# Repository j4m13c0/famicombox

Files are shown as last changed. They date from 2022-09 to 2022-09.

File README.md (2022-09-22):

Main Board

The FamicomBox+ mod has been designed to fix some of the design limitations in the Famicom Box design. The Famicom Box is designed to switch between 16 different cartridges, however in the original design some of the pins in the cartridge are common between the 16 cartridges such as IRQ, M2 and PPU /RD. This mod addresses the following issues:

* Demultiplexes M2 (Pin 38) to all 16 Cartridges
* Multiplexes /IRQ (Pin 15) from all 16 cartridges
* Multiplexes CIRAM /CE (Pin 57) from all 16 cartirdges
* Demultiplexes PPU A12 (pin 64) to all 16 Cartridges
* Demultiplexes PPU /RD (Pin 21) to all 16 Cartridges
* Supplies PPU /A13 (Pin 58) to all cartridges
* Isolates EXP0, EXP1, EXP2, EXP3, EXP4, EXP5, EXP7, EXP8 and EXP9 
* Allows 2 cartridges to utilise EXP6 for Expansion Audio with volume control. 
* Fixes an issue with open bus on games such as Paper Boy
* Disables the second RAM chip 6000 - 7FFF when in game, to allow SRAM and other functions. 
* Enables / Disables $5xxx when in game, this is used in some games and the Everdrive. 

### Famicom Box Warning

On a stock Famicom Box, the EXP Lines are connected to 5V or GND depending on which slot you use. This is used with the CIC to address each CIC individually. Some cartridges use these ports for debugging, Audio etc. If you have a stock Famicom Box you will damage certain cartridge if you plug them in.

### Limitations
This mod is rather complicated to install as there are many parts that you will need to modify to get it to work. You will need to have prior experience with de-soldering IC chips, soldering mod wires and debugging any issues that arise. 
This mod will not work with modern games that have tighter timings, as well as bootleg games bought from places such as AliExpress. 

### Tested Games
I have tested this with the following games:

* Castlevania 3 (Famicom with Expansion Audio)
* The Legend of Zelda
* The Adventure of Link
* Super Mario Bros
* Super Mario Bros 2
* Super Mario Bros 3
* Gauntlet II
* Tetris
* Snake Rattle N Roll
* The Little Mermaid
* Excitebike
* Tennis
* Duck Hunt
* Wrecking Crew
* Captain Planet and the Planeteers
* High Speed
* Yoshi 

I have also been able to use the Famicom Disk System, the RAM adapter will fit in Slot 14. The mod also works with an Everdrive. 

__There may be some games that will not work on this system. This could be down to timing issues. I cannot guarantee any game will work outside of the games tested.__

### Menu System 
The Menu system has been designed by Nintendo to check an internal database of games or for the Nintendo Header in the ROM. Most games do not have a correct header and will not be in the database, thus the game will be rejected. 
 
To get around this, we have modified the menu to still allow games to show up in the menu, however it will only display "NES GAME" instead of the actual game name. 

### 3D Prints
I have included some 3D prints that have used with the Famicom Box.  
 
The Modulator 3D print I used to replace the modulator with some custom connectors with my Famicom Box, I had fitted an NESRGB and this was where I mounted the video and audio connections. This is not required, but added incase you also want to RGB yours. 

The Replacement Coin box covers are the 2 covers on the right-hand side. If you remove the coinbox, you will need these to cover up the holes. 

The 72 Pin connector spacer is helpful if you use the Aliexpress connectors. See the installation guide for more details. 

### Special Thanks

I would like to thank Lidnariq for his time and knowledge to help me make this idea a reality, he was there to teach me what parts were different between the Famicom Box and what parts to include on my mod board. 

I would also like to extend a thank you to Fiskbit, who has helped with reverse engineering the Menu software and modifying it to allow other games to function. He has also improved the menu and fixed some bugs. 
The boot up of the console is now drastically improved due to changes made to the menu.

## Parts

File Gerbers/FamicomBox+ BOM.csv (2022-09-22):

Part | Value | Mouser PN
C1 | 100nF | 581-06035C104KAT2A
C2 | 100nF | 581-06035C104KAT2A
C3 | 100nF | 581-06035C104KAT2A
C4 | 100nF | 581-06035C104KAT2A
C5 | 100nF | 581-06035C104KAT2A
C6 | 100nF | 581-06035C104KAT2A
C7 | 100nF | 581-06035C104KAT2A
C8 | 100nF | 581-06035C104KAT2A
C9 | 100nF | 581-06035C104KAT2A
C10 | 100nF | 581-06035C104KAT2A
C12 | 100nF | 581-06035C104KAT2A
C13 | 100nF | 581-06035C104KAT2A
C15 | 100nF | 581-06035C104KAT2A
C16 | 100nF | 581-06035C104KAT2A
IC1 | 74HC138PW,118 | 771-74HC138PW-T
IC2 | 74HC138PW,118 | 771-74HC138PW-T
IC3 | SN74HC251NSR | 595-SN74HC251NSR
IC4 | SN74HC251NSR | 595-SN74HC251NSR
IC5 | MC74HC04ADG | 863-MC74HC04ADG
IC6 | SN74CBT3245APWR | 595-SN74CBT3245APWR
IC7 | SN74CBT3245APWR | 595-SN74CBT3245APWR
IC8 | SN74CBT3245APWR | 595-SN74CBT3245APWR
IC9 | SN74HC251NSR | 595-SN74HC251NSR
IC10 | SN74HC251NSR | 595-SN74HC251NSR
IC11 | SN74ALS138AN | 595-SN74ALS138AN
IC12 | CD74HC238PWR | 595-CD74HC238PWR
IC13 | CD74HC238PWR | 595-CD74HC238PWR
IC16 | 74HC138PW,118 | 771-74HC138PW-T
IC17 | 74HC138PW,118 | 771-74HC138PW-T
J1 | Pin Strip
J2 | Pin Strip
J3 | Pin Strip
J4 | Pin Strip
J5 | Pin Strip
J6 | Pin Strip
J7 | Pin Strip
J8 | Pin Strip
J9 | 2-5499206-1 | 571-2-5499206-1
J9 Cable Conn | 1658527-4 | 571-1658527-4
J10 | 2-5499206-6 | 571-2-5499206-6
J10 Cable Conn | 1-1658527-0 | 571-1-1658527-0
J11 | 2-5499206-6 | 571-2-5499206-6
J11 Cable Conn | 1-1658527-0 | 571-1-1658527-0
J12 | 2-5499206-6 | 571-2-5499206-6
J12 Cable Conn | 1-1658527-0 | 571-1-1658527-0
R1 | PTV09A-4020F-A504 | 652-PTV09A-4020FA504
R2 | 1.5K | CR0603-FX-1501ELF
R3 | 1.5K | CR0603-FX-1501ELF
RN1 | CAY17-103JALF | 652-CAY17-103JALF
RN2 | CAY17-103JALF | 652-CAY17-103JALF
RN3 | 4816P-T01-101LF | 652-4816P-T1LF-100
RN4 | 4816P-T01-101LF | 652-4816P-T1LF-100
RN5 | 4816P-T01-101LF | 652-4816P-T1LF-100

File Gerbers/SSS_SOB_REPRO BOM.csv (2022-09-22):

Part | Value | Mouser
C1 | 100nf | 581-06035C104KAT2A
C2 | 100nf | 581-06035C104KAT2A
C3 | 100nf | 581-06035C104KAT2A
C4 | 100nf | 581-06035C104KAT2A
C5 | 100nf | 581-06035C104KAT2A
C6 | 100nf | 581-06035C104KAT2A
C7 | 100nf | 581-06035C104KAT2A
C8 | 100nf | 581-06035C104KAT2A
C9 | 220uf 10V | 647-UFW1A221MED
C10 | 220uf 10V | 647-UFW1A221MED
J1 | 2-5499206-6 | 571-2-5499206-6
J1 Cable Conn | 1-1658527-0 | 571-1-1658527-0
J2 | 2-5499206-6 | 571-2-5499206-6
J2 Cable Conn | 1-1658527-0 | 571-1-1658527-0
J3 | 2-5499206-6 | 571-2-5499206-6
J3 Cable Conn | 1-1658527-0 | 571-1-1658527-0
P1 | CARTRIDGE_CONNECTOR | https://www.aliexpress.com/item/32785406388.html
P2 | CARTRIDGE_CONNECTOR | https://www.aliexpress.com/item/32785406388.html
P3 | CARTRIDGE_CONNECTOR | https://www.aliexpress.com/item/32785406388.html
P4 | CARTRIDGE_CONNECTOR | https://www.aliexpress.com/item/32785406388.html
P5 | CARTRIDGE_CONNECTOR | https://www.aliexpress.com/item/32785406388.html
P6 | CARTRIDGE_CONNECTOR | https://www.aliexpress.com/item/32785406388.html
P7 | CARTRIDGE_CONNECTOR | https://www.aliexpress.com/item/32785406388.html
P8 | CARTRIDGE_CONNECTOR | https://www.aliexpress.com/item/32785406388.html
P9 | CARTRIDGE_CONNECTOR | https://www.aliexpress.com/item/32785406388.html
P10 | CARTRIDGE_CONNECTOR | https://www.aliexpress.com/item/32785406388.html
P11 | CARTRIDGE_CONNECTOR | https://www.aliexpress.com/item/32785406388.html
P12 | CARTRIDGE_CONNECTOR | https://www.aliexpress.com/item/32785406388.html
P13 | CARTRIDGE_CONNECTOR | https://www.aliexpress.com/item/32785406388.html
P14 | CARTRIDGE_CONNECTOR | https://www.aliexpress.com/item/32785406388.html
P15 | CARTRIDGE_CONNECTOR | https://www.aliexpress.com/item/32785406388.html
P16 | CARTRIDGE_CONNECTOR | https://www.aliexpress.com/item/32785406388.html
P17 | CARTRIDGE_CONNECTOR | https://www.aliexpress.com/item/32785406388.html
P18 | CARTRIDGE_CONNECTOR | https://www.aliexpress.com/item/32785406388.html
P19 | LED_BOARD_CONNECTOR | B7B-PH-K-S(LF)(SN)
P20 | LED_BOARD_CONNECTOR | B7B-PH-K-S(LF)(SN)
P21 | LED_BOARD_CONNECTOR | B7B-PH-K-S(LF)(SN)

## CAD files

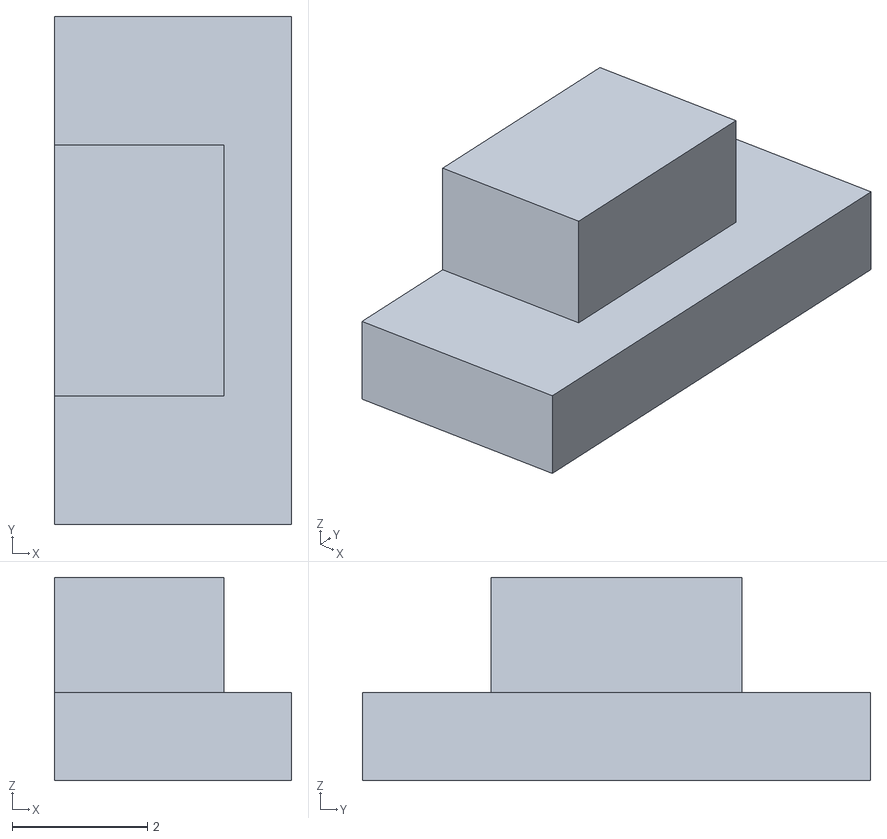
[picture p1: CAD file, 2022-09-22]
3D Models/72Pin Connector Spacer/72pin Insert v1.stl
3.50 x 7.50 x 3.00

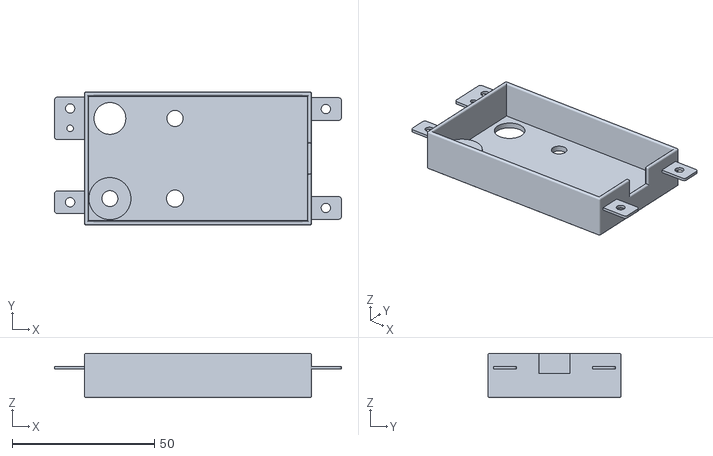
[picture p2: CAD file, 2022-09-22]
3D Models/Modulator/Modulator Famicom Box v7.stl
101.0 x 46.8 x 15.5

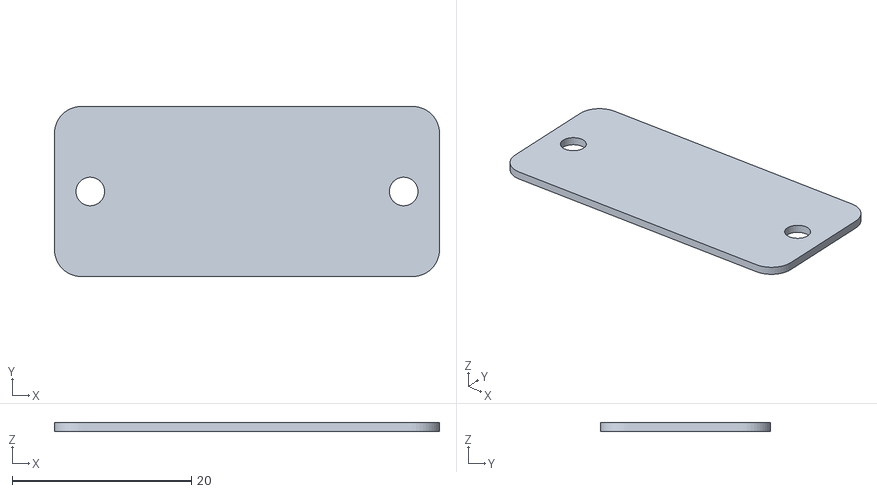
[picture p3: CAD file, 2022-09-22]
3D Models/Replacement Coin box Cover/Famicom Box Coinbox Cover Small v1.stl
43.0 x 19.0 x 1.00

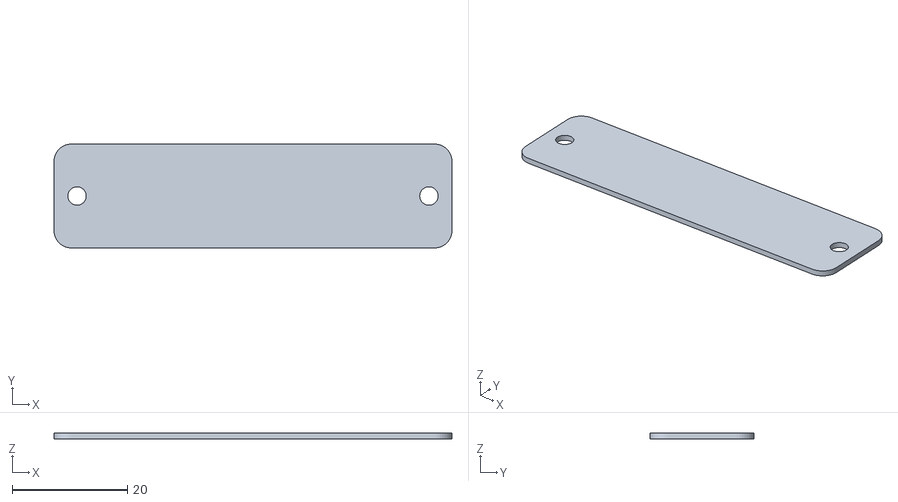
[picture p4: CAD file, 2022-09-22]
3D Models/Replacement Coin box Cover/Famicom Box Coinbox Cover Large v1.stl
69.0 x 18.0 x 1.00

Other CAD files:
3D Models/72Pin Connector Spacer/72pin Insert v1.f3d
3D Models/Modulator/Modulator Famicom Box v7.f3d
3D Models/Replacement Coin box Cover/Famicom Box Coinbox Cover Large v1.f3d
3D Models/Replacement Coin box Cover/Famicom Box Coinbox Cover Small v1.f3d

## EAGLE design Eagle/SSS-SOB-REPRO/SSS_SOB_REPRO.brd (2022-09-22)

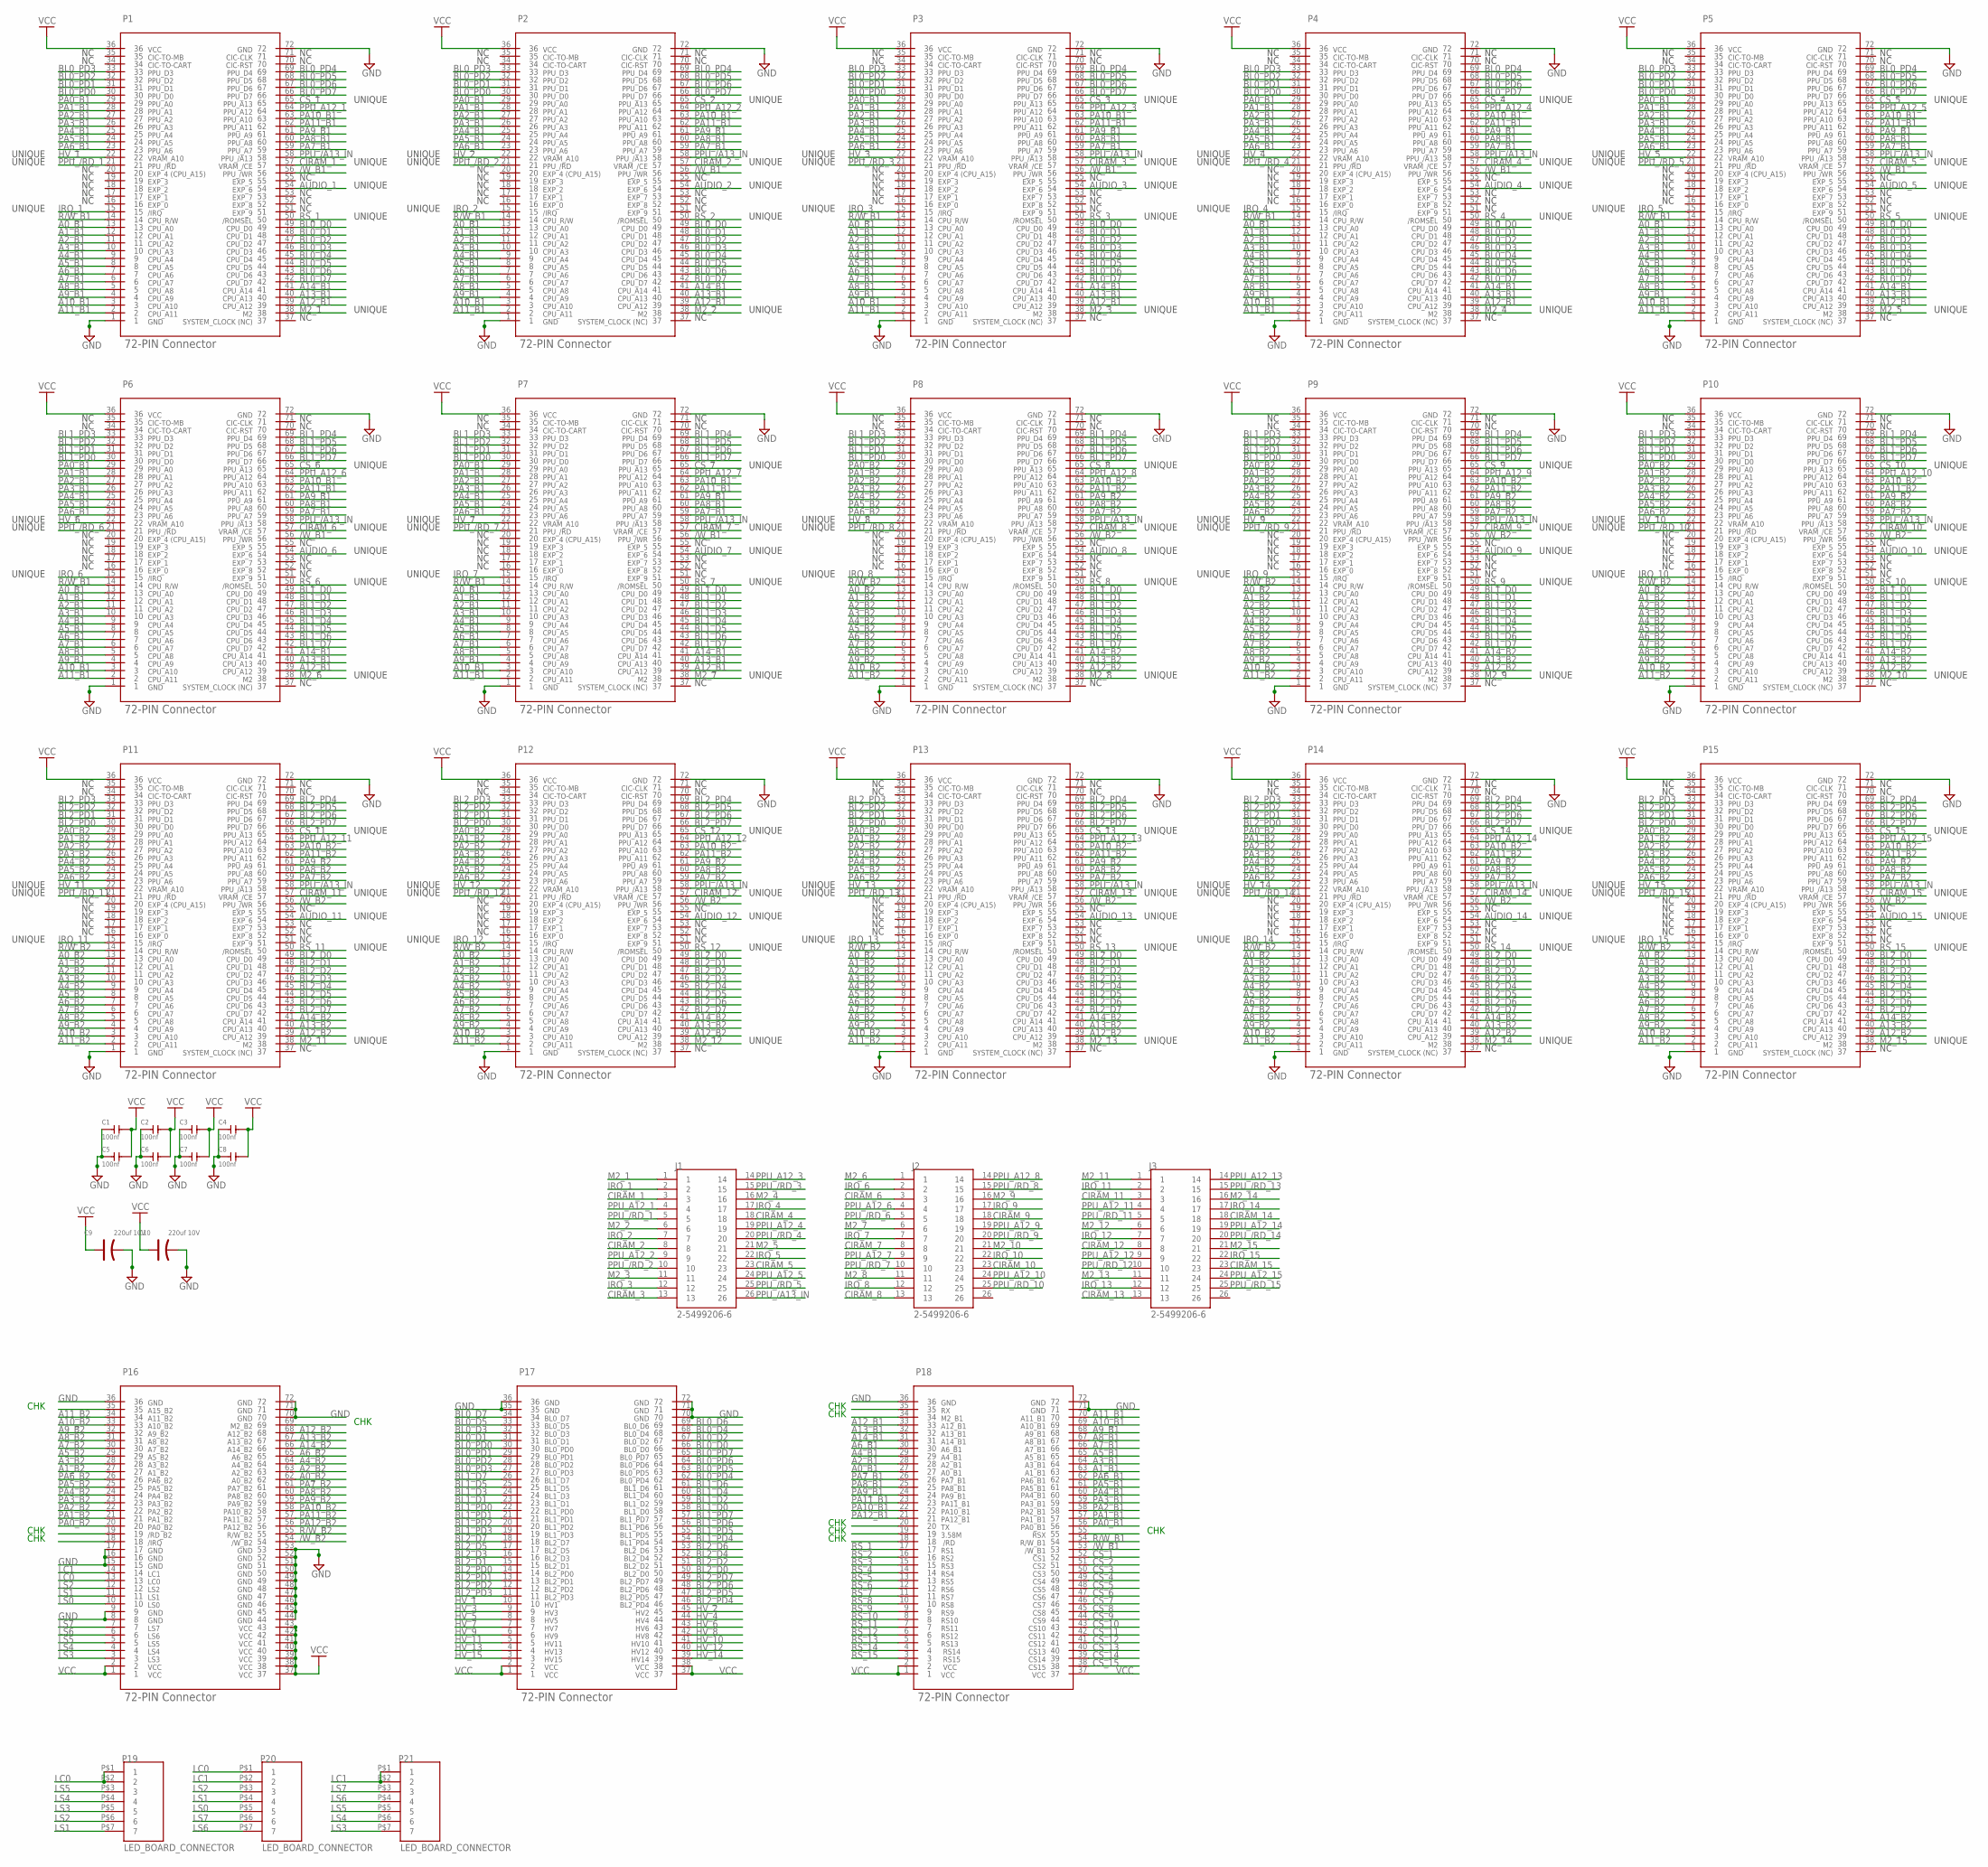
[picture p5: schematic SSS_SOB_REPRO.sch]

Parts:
C1, C2, C3, C4, C5, C6, C7, C8: 100nf; C0603
C9, C10: 220uf 10V; PC-D5.3MM
J1, J2, J3: 2-5499206-6; TE_2-5499206-6
P1, P2, P3, P4, P5, P6, P7, P8, P9, P10, P11, P12, P13, P14, P15: CARTRIDGE_CONNECTOR; 72PIN
P16: P16_CONNECTOR; 72PIN
P17: P17_CONNECTOR; 72PIN
P18: P18_CONNECTOR; 72PIN
P19, P20, P21: LED_BOARD_CONNECTOR; 7PIN_LED

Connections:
/RD_B2: P16.19
/W_B1: P1.56, P2.56, P3.56, P4.56, P5.56, P6.56, P7.56, P18.53
/W_B2: P8.56, P9.56, P10.56, P11.56, P12.56, P13.56, P14.56, P15.56, P16.54
A0_B1: P1.13, P2.13, P3.13, P4.13, P5.13, P6.13, P7.13, P18.27
A0_B2: P8.13, P9.13, P10.13, P11.13, P12.13, P13.13, P14.13, P15.13, P16.62
A1_B1: P1.12, P2.12, P3.12, P4.12, P5.12, P6.12, P7.12, P18.63
A1_B2: P8.12, P9.12, P10.12, P11.12, P12.12, P13.12, P14.12, P15.12, P16.27
A2_B1: P1.11, P2.11, P3.11, P4.11, P5.11, P6.11, P7.11, P18.28
A2_B2: P8.11, P9.11, P10.11, P11.11, P12.11, P13.11, P14.11, P15.11, P16.63
A3_B1: P1.10, P2.10, P3.10, P4.10, P5.10, P6.10, P7.10, P18.64
A3_B2: P8.10, P9.10, P10.10, P11.10, P12.10, P13.10, P14.10, P15.10, P16.28
A4_B1: P1.9, P2.9, P3.9, P4.9, P5.9, P6.9, P7.9, P18.29
A4_B2: P8.9, P9.9, P10.9, P11.9, P12.9, P13.9, P14.9, P15.9, P16.64
A5_B1: P1.8, P2.8, P3.8, P4.8, P5.8, P6.8, P7.8, P18.65
A5_B2: P8.8, P9.8, P10.8, P11.8, P12.8, P13.8, P14.8, P15.8, P16.29
A6_B1: P1.7, P2.7, P3.7, P4.7, P5.7, P6.7, P7.7, P18.30
A6_B2: P8.7, P9.7, P10.7, P11.7, P12.7, P13.7, P14.7, P15.7, P16.65
A7_B1: P1.6, P2.6, P3.6, P4.6, P5.6, P6.6, P7.6, P18.66
A7_B2: P8.6, P9.6, P10.6, P11.6, P12.6, P13.6, P14.6, P15.6, P16.30
A8_B1: P1.5, P2.5, P3.5, P4.5, P5.5, P6.5, P7.5, P18.67
A8_B2: P8.5, P9.5, P10.5, P11.5, P12.5, P13.5, P14.5, P15.5, P16.31
A9_B1: P1.4, P2.4, P3.4, P4.4, P5.4, P6.4, P7.4, P18.68
A9_B2: P8.4, P9.4, P10.4, P11.4, P12.4, P13.4, P14.4, P15.4, P16.32
A10_B1: P1.3, P2.3, P3.3, P4.3, P5.3, P6.3, P7.3, P18.69
A10_B2: P8.3, P9.3, P10.3, P11.3, P12.3, P13.3, P14.3, P15.3, P16.33
A11_B1: P1.2, P2.2, P3.2, P4.2, P5.2, P6.2, P7.2, P18.70
A11_B2: P8.2, P9.2, P10.2, P11.2, P12.2, P13.2, P14.2, P15.2, P16.34
A12_B1: P1.39, P2.39, P3.39, P4.39, P5.39, P6.39, P7.39, P18.33
A12_B2: P8.39, P9.39, P10.39, P11.39, P12.39, P13.39, P14.39, P15.39, P16.68
A13_B1: P1.40, P2.40, P3.40, P4.40, P5.40, P6.40, P7.40, P18.32
A13_B2: P8.40, P9.40, P10.40, P11.40, P12.40, P13.40, P14.40, P15.40, P16.67
A14_B1: P1.41, P2.41, P3.41, P4.41, P5.41, P6.41, P7.41, P18.31
A14_B2: P8.41, P9.41, P10.41, P11.41, P12.41, P13.41, P14.41, P15.41, P16.66
A15_B2: P16.35
AUDIO_1: P1.54
AUDIO_2: P2.54
AUDIO_3: P3.54
AUDIO_4: P4.54
AUDIO_5: P5.54
AUDIO_6: P6.54
AUDIO_7: P7.54
AUDIO_8: P8.54
AUDIO_9: P9.54
AUDIO_10: P10.54
AUDIO_11: P11.54
AUDIO_12: P12.54
AUDIO_13: P13.54
AUDIO_14: P14.54
AUDIO_15: P15.54
BL0_D0: P1.49, P2.49, P3.49, P4.49, P5.49, P17.66
BL0_D1: P1.48, P2.48, P3.48, P4.48, P5.48, P17.31
BL0_D2: P1.47, P2.47, P3.47, P4.47, P5.47, P17.67
BL0_D3: P1.46, P2.46, P3.46, P4.46, P5.46, P17.32
BL0_D4: P1.45, P2.45, P3.45, P4.45, P5.45, P17.68
BL0_D5: P1.44, P2.44, P3.44, P4.44, P5.44, P17.33
BL0_D6: P1.43, P2.43, P3.43, P4.43, P5.43, P17.69
BL0_D7: P1.42, P2.42, P3.42, P4.42, P5.42, P17.34
BL0_PD0: P1.30, P2.30, P3.30, P4.30, P5.30, P17.30
BL0_PD1: P1.31, P2.31, P3.31, P4.31, P5.31, P17.29
BL0_PD2: P1.32, P2.32, P3.32, P4.32, P5.32, P17.28
BL0_PD3: P1.33, P2.33, P3.33, P4.33, P5.33, P17.27
BL0_PD4: P1.69, P2.69, P3.69, P4.69, P5.69, P17.62
BL0_PD5: P1.68, P2.68, P3.68, P4.68, P5.68, P17.63
BL0_PD6: P1.67, P2.67, P3.67, P4.67, P5.67, P17.64
BL0_PD7: P1.66, P2.66, P3.66, P4.66, P5.66, P17.65
BL1_D0: P6.49, P7.49, P8.49, P9.49, P10.49, P17.58
BL1_D1: P6.48, P7.48, P8.48, P9.48, P10.48, P17.23
BL1_D2: P6.47, P7.47, P8.47, P9.47, P10.47, P17.59
BL1_D3: P6.46, P7.46, P8.46, P9.46, P10.46, P17.24
BL1_D4: P6.45, P7.45, P8.45, P9.45, P10.45, P17.60
BL1_D5: P6.44, P7.44, P8.44, P9.44, P10.44, P17.25
BL1_D6: P6.43, P7.43, P8.43, P9.43, P10.43, P17.61
BL1_D7: P6.42, P7.42, P8.42, P9.42, P10.42, P17.26
BL1_PD0: P6.30, P7.30, P8.30, P9.30, P10.30, P17.22
BL1_PD1: P6.31, P7.31, P8.31, P9.31, P10.31, P17.21
BL1_PD2: P6.32, P7.32, P8.32, P9.32, P10.32, P17.20
BL1_PD3: P6.33, P7.33, P8.33, P9.33, P10.33, P17.19
BL1_PD4: P6.69, P7.69, P8.69, P9.69, P10.69, P17.54
BL1_PD5: P6.68, P7.68, P8.68, P9.68, P10.68, P17.55
BL1_PD6: P6.67, P7.67, P8.67, P9.67, P10.67, P17.56
BL1_PD7: P6.66, P7.66, P8.66, P9.66, P10.66, P17.57
BL2_D0: P11.49, P12.49, P13.49, P14.49, P15.49, P17.50
BL2_D1: P11.48, P12.48, P13.48, P14.48, P15.48, P17.15
BL2_D2: P11.47, P12.47, P13.47, P14.47, P15.47, P17.51
BL2_D3: P11.46, P12.46, P13.46, P14.46, P15.46, P17.16
BL2_D4: P11.45, P12.45, P13.45, P14.45, P15.45, P17.52
BL2_D5: P11.44, P12.44, P13.44, P14.44, P15.44, P17.17
BL2_D6: P11.43, P12.43, P13.43, P14.43, P15.43, P17.53
BL2_D7: P11.42, P12.42, P13.42, P14.42, P15.42, P17.18
BL2_PD0: P11.30, P12.30, P13.30, P14.30, P15.30, P17.14
BL2_PD1: P11.31, P12.31, P13.31, P14.31, P15.31, P17.13
BL2_PD2: P11.32, P12.32, P13.32, P14.32, P15.32, P17.12
BL2_PD3: P11.33, P12.33, P13.33, P14.33, P15.33, P17.11
BL2_PD4: P11.69, P12.69, P13.69, P14.69, P15.69, P17.46
BL2_PD5: P11.68, P12.68, P13.68, P14.68, P15.68, P17.47
BL2_PD6: P11.67, P12.67, P13.67, P14.67, P15.67, P17.48
BL2_PD7: P11.66, P12.66, P13.66, P14.66, P15.66, P17.49
CIRAM_1: J1.3, P1.57
CIRAM_2: J1.8, P2.57
CIRAM_3: J1.13, P3.57
CIRAM_4: J1.18, P4.57
CIRAM_5: J1.23, P5.57
CIRAM_6: J2.3, P6.57
CIRAM_7: J2.8, P7.57
CIRAM_8: J2.13, P8.57
CIRAM_9: J2.18, P9.57
CIRAM_10: J2.23, P10.57
CIRAM_11: J3.3, P11.57
CIRAM_12: J3.8, P12.57
CIRAM_13: J3.13, P13.57
CIRAM_14: J3.18, P14.57
CIRAM_15: J3.23, P15.57
CS_1: P1.65, P18.52
CS_2: P2.65, P18.51
CS_3: P3.65, P18.50
CS_4: P4.65, P18.49
CS_5: P5.65, P18.48
CS_6: P6.65, P18.47
CS_7: P7.65, P18.46
CS_8: P8.65, P18.45
CS_9: P9.65, P18.44
CS_10: P10.65, P18.43
CS_11: P11.65, P18.42
CS_12: P12.65, P18.41
CS_13: P13.65, P18.40
CS_14: P14.65, P18.39
CS_15: P15.65, P18.38
GND: C1.1, C2.1, C3.1, C4.1, C5.1, C6.1, C7.1, C8.1, C9.-, C10.-, P1.1, P1.72, P2.1, P2.72, P3.1, P3.72, P4.1, P4.72, P5.1, P5.72, P6.1, P6.72, P7.1, P7.72, P8.1, P8.72, P9.1, P9.72, P10.1, P10.72, P11.1, P11.72, P12.1, P12.72, P13.1, P13.72, P14.1, P14.72, P15.1, P15.72, P16.8, P16.9, P16.15, P16.16, P16.17, P16.36, P16.44, P16.45, P16.46, P16.47, P16.48, P16.49, P16.50, P16.51, P16.52, P16.53, P16.70, P16.71, P16.72, P17.35, P17.36, P17.70, P17.71, P17.72, P18.36, P18.71, P18.72
HV_1: P1.22, P17.10
HV_2: P2.22, P17.45
HV_3: P3.22, P17.9
HV_4: P4.22, P17.44
HV_5: P5.22, P17.8
HV_6: P6.22, P17.43
HV_7: P7.22, P17.7
HV_8: P8.22, P17.42
HV_9: P9.22, P17.6
HV_10: P10.22, P17.41
HV_11: P11.22, P17.5
HV_12: P12.22, P17.40
HV_13: P13.22, P17.4
HV_14: P14.22, P17.39
HV_15: P15.22, P17.3
IRQ_1: J1.2, P1.15
IRQ_2: J1.7, P2.15
IRQ_3: J1.12, P3.15
IRQ_4: J1.17, P4.15
IRQ_5: J1.22, P5.15
IRQ_6: J2.2, P6.15
IRQ_7: J2.7, P7.15
IRQ_8: J2.12, P8.15
IRQ_9: J2.17, P9.15
IRQ_10: J2.22, P10.15
IRQ_11: J3.2, P11.15
IRQ_12: J3.7, P12.15
IRQ_13: J3.12, P13.15
IRQ_14: J3.17, P14.15
IRQ_15: J3.22, P15.15
LC0: P16.13, P19.P$1 (1), P19.P$2 (2), P20.P$1 (1)
LC1: P16.14, P20.P$2 (2), P21.P$1 (1), P21.P$2 (2)
LS0: P16.10, P20.P$5 (5)
LS1: P16.11, P19.P$7 (7), P20.P$4 (4)
LS2: P16.12, P19.P$6 (6), P20.P$3 (3)
LS3: P16.3, P19.P$5 (5), P21.P$7 (7)
LS4: P16.4, P19.P$4 (4), P21.P$6 (6)
LS5: P16.5, P19.P$3 (3), P21.P$5 (5)
LS6: P16.6, P20.P$7 (7), P21.P$4 (4)
LS7: P16.7, P20.P$6 (6), P21.P$3 (3)
M2_1: J1.1, P1.38
M2_2: J1.6, P2.38
M2_3: J1.11, P3.38
M2_4: J1.16, P4.38
M2_5: J1.21, P5.38
M2_6: J2.1, P6.38
M2_7: J2.6, P7.38
M2_8: J2.11, P8.38
M2_9: J2.16, P9.38
M2_10: J2.21, P10.38
M2_11: J3.1, P11.38
M2_12: J3.6, P12.38
M2_13: J3.11, P13.38
M2_14: J3.16, P14.38
M2_15: J3.21, P15.38
PA0_B1: P1.29, P2.29, P3.29, P4.29, P5.29, P6.29, P7.29, P18.56
PA0_B2: P8.29, P9.29, P10.29, P11.29, P12.29, P13.29, P14.29, P15.29, P16.20
PA1_B1: P1.28, P2.28, P3.28, P4.28, P5.28, P6.28, P7.28, P18.57
PA1_B2: P8.28, P9.28, P10.28, P11.28, P12.28, P13.28, P14.28, P15.28, P16.21
PA2_B1: P1.27, P2.27, P3.27, P4.27, P5.27, P6.27, P7.27, P18.58
PA2_B2: P8.27, P9.27, P10.27, P11.27, P12.27, P13.27, P14.27, P15.27, P16.22
PA3_B1: P1.26, P2.26, P3.26, P4.26, P5.26, P6.26, P7.26, P18.59
PA3_B2: P8.26, P9.26, P10.26, P11.26, P12.26, P13.26, P14.26, P15.26, P16.23
PA4_B1: P1.25, P2.25, P3.25, P4.25, P5.25, P6.25, P7.25, P18.60
PA4_B2: P8.25, P9.25, P10.25, P11.25, P12.25, P13.25, P14.25, P15.25, P16.24
PA5_B1: P1.24, P2.24, P3.24, P4.24, P5.24, P6.24, P7.24, P18.61
PA5_B2: P8.24, P9.24, P10.24, P11.24, P12.24, P13.24, P14.24, P15.24, P16.25
PA6_B1: P1.23, P2.23, P3.23, P4.23, P5.23, P6.23, P7.23, P18.62
PA6_B2: P8.23, P9.23, P10.23, P11.23, P12.23, P13.23, P14.23, P15.23, P16.26
PA7_B1: P1.59, P2.59, P3.59, P4.59, P5.59, P6.59, P7.59, P18.26
PA7_B2: P8.59, P9.59, P10.59, P11.59, P12.59, P13.59, P14.59, P15.59, P16.61
PA8_B1: P1.60, P2.60, P3.60, P4.60, P5.60, P6.60, P7.60, P18.25
PA8_B2: P8.60, P9.60, P10.60, P11.60, P12.60, P13.60, P14.60, P15.60, P16.60
PA9_B1: P1.61, P2.61, P3.61, P4.61, P5.61, P6.61, P7.61, P18.24
PA9_B2: P8.61, P9.61, P10.61, P11.61, P12.61, P13.61, P14.61, P15.61, P16.59
PA10_B1: P1.63, P2.63, P3.63, P4.63, P5.63, P6.63, P7.63, P18.22
PA10_B2: P8.63, P9.63, P10.63, P11.63, P12.63, P13.63, P14.63, P15.63, P16.58
PA11_B1: P1.62, P2.62, P3.62, P4.62, P5.62, P6.62, P7.62, P18.23
PA11_B2: P8.62, P9.62, P10.62, P11.62, P12.62, P13.62, P14.62, P15.62, P16.57
PA12_B1: P18.21
PA12_B2: P16.56
PPU_/A13_IN: J1.26, P1.58, P2.58, P3.58, P4.58, P5.58, P6.58, P7.58, P8.58, P9.58, P10.58, P11.58, P12.58, P13.58, P14.58, P15.58
PPU_/RD_1: J1.5, P1.21
PPU_/RD_2: J1.10, P2.21
PPU_/RD_3: J1.15, P3.21
PPU_/RD_4: J1.20, P4.21
PPU_/RD_5: J1.25, P5.21
PPU_/RD_6: J2.5, P6.21
PPU_/RD_7: J2.10, P7.21
PPU_/RD_8: J2.15, P8.21
PPU_/RD_9: J2.20, P9.21
PPU_/RD_10: J2.25, P10.21
PPU_/RD_11: J3.5, P11.21
PPU_/RD_12: J3.10, P12.21
PPU_/RD_13: J3.15, P13.21
PPU_/RD_14: J3.20, P14.21
PPU_/RD_15: J3.25, P15.21
PPU_A12_1: J1.4, P1.64
PPU_A12_2: J1.9, P2.64
PPU_A12_3: J1.14, P3.64
PPU_A12_4: J1.19, P4.64
PPU_A12_5: J1.24, P5.64
PPU_A12_6: J2.4, P6.64
PPU_A12_7: J2.9, P7.64
PPU_A12_8: J2.14, P8.64
PPU_A12_9: J2.19, P9.64
PPU_A12_10: J2.24, P10.64
PPU_A12_11: J3.4, P11.64
PPU_A12_12: J3.9, P12.64
PPU_A12_13: J3.14, P13.64
PPU_A12_14: J3.19, P14.64
PPU_A12_15: J3.24, P15.64
R/W_B1: P1.14, P2.14, P3.14, P4.14, P5.14, P6.14, P7.14, P18.54
R/W_B2: P8.14, P9.14, P10.14, P11.14, P12.14, P13.14, P14.14, P15.14, P16.55
RS_1: P1.50, P18.17
RS_2: P2.50, P18.16
RS_3: P3.50, P18.15
RS_4: P4.50, P18.14
RS_5: P5.50, P18.13
RS_6: P6.50, P18.12
RS_7: P7.50, P18.11
RS_8: P8.50, P18.10
RS_9: P9.50, P18.9
RS_10: P10.50, P18.8
RS_11: P11.50, P18.7
RS_12: P12.50, P18.6
RS_13: P13.50, P18.5
RS_14: P14.50, P18.4
RS_15: P15.50, P18.3
VCC: C1.2, C2.2, C3.2, C4.2, C5.2, C6.2, C7.2, C8.2, C9.+, C10.+, P1.36, P2.36, P3.36, P4.36, P5.36, P6.36, P7.36, P8.36, P9.36, P10.36, P11.36, P12.36, P13.36, P14.36, P15.36, P16.1, P16.2, P16.37, P16.38, P16.39, P16.40, P16.41, P16.42, P16.43, P17.1, P17.2, P17.37, P17.38, P18.1, P18.2, P18.37

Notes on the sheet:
UNIQUE
CHK

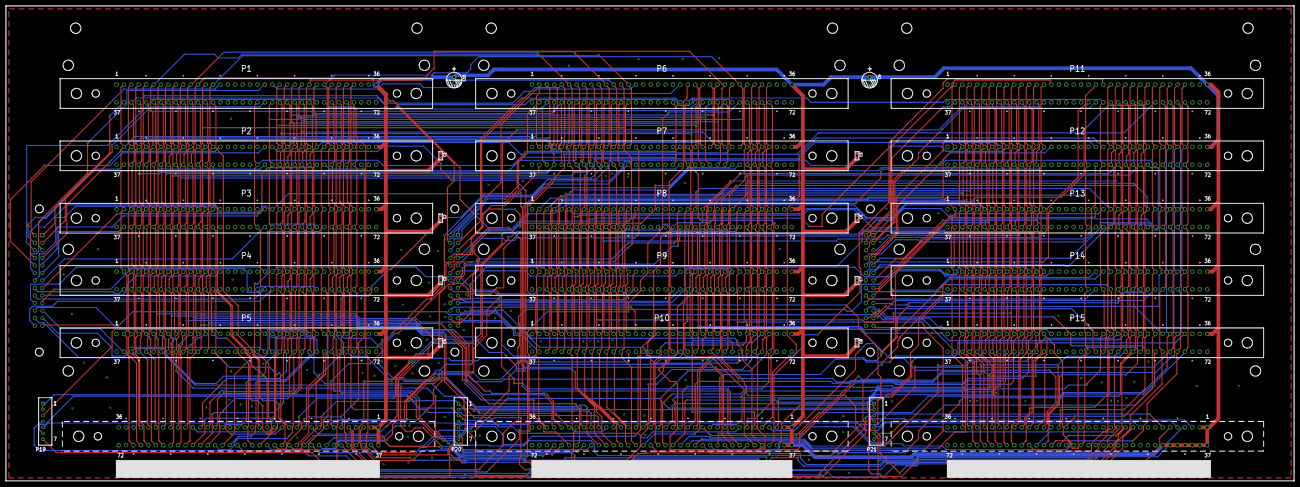
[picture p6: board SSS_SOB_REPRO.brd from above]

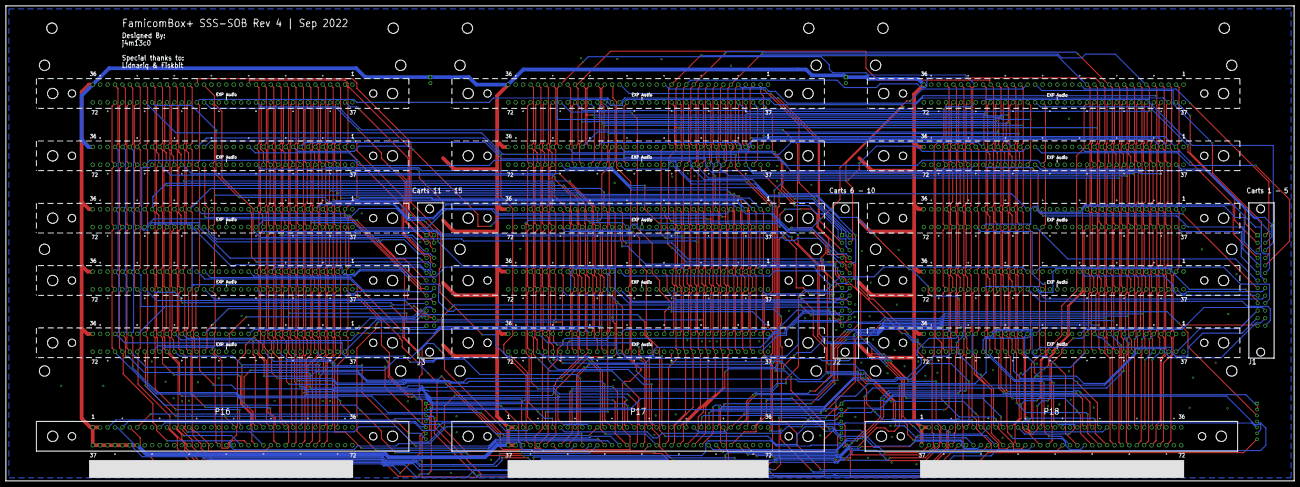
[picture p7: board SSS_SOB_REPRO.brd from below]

Board: 2 copper layers, 434.0 x 160.0 mm, 34 parts (6 on the bottom side), 239 nets.

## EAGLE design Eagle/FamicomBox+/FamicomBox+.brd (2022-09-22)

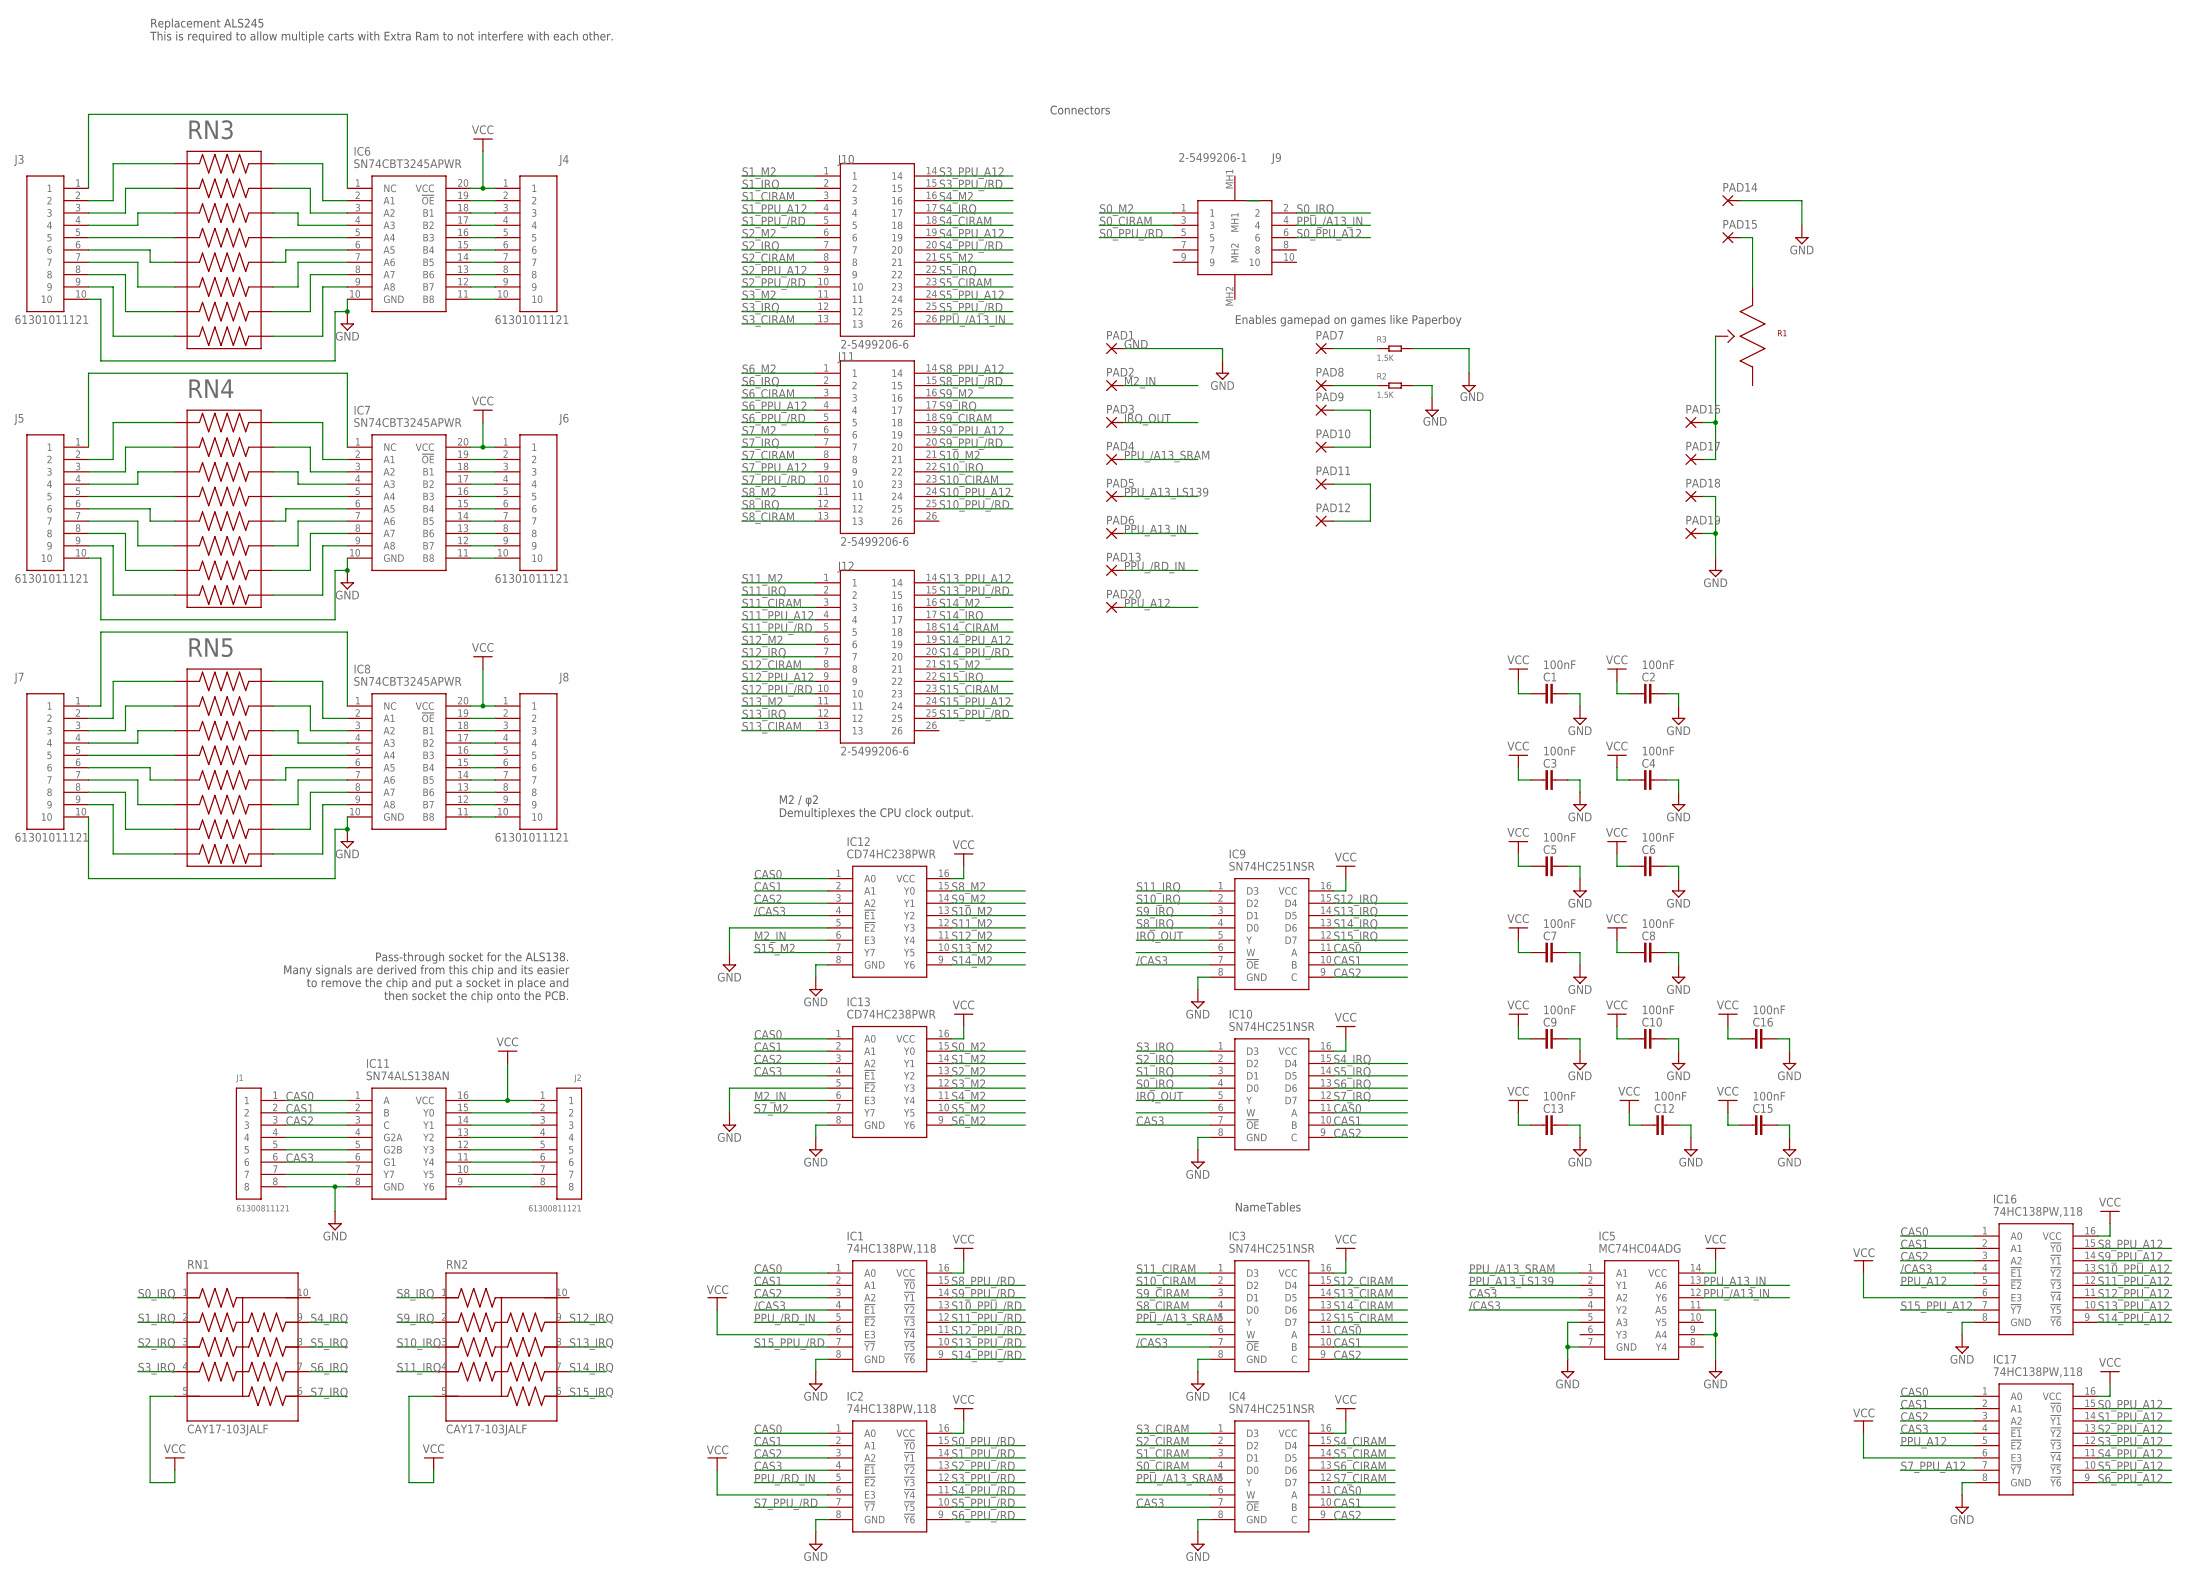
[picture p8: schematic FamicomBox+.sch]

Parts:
C1, C2, C3, C4, C5, C6, C7, C8, C9, C10, C12, C13, C15, C16: 100nF; CAPC1608X85
IC1, IC2, IC16, IC17: 74HC138PW,118; SOP65P640X110-16N
IC3, IC4, IC9, IC10: SN74HC251NSR; SOIC127P780X200-16N
IC5: MC74HC04ADG; SOIC127P600X175-14N
IC6, IC7, IC8: SN74CBT3245APWR; SOP65P640X120-20N
IC11: SN74ALS138AN; DIP254P762X508-16
IC12, IC13: CD74HC238PWR; SOP65P640X120-16N
J1, J2: 61300811121
J3, J4, J5, J6, J7, J8: 61301011121
J9: 2-5499206-1; 254992061
J10, J11, J12: 2-5499206-6; TE_2-5499206-6
PAD1, PAD2, PAD3, PAD4, PAD5, PAD6, PAD7, PAD8, PAD9, PAD10, PAD11, PAD12, PAD13, PAD14, PAD15, PAD16, PAD17, PAD18, PAD19, PAD20: WIREPAD2,54/1,0; 2,54/1,0
R1: PTV09A-4020F-A504; PTV09
R2, R3: 1.5K; R0603
RN1, RN2: CAY17-103JALF; RESCAXS64P320X160X60-10N
RN3, RN4, RN5: 4816P-1-562LF; SOIC127P762X240-16N

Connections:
/CAS3: IC1.4 (!E1), IC3.7 (!OE), IC5.4 (Y2), IC9.7 (!OE), IC12.4 (!E1), IC16.4 (!E1)
CAS0: IC1.1 (A0), IC2.1 (A0), IC3.11 (A), IC4.11 (A), IC9.11 (A), IC10.11 (A), IC11.1 (A), IC12.1 (A0), IC13.1 (A0), IC16.1 (A0), IC17.1 (A0), J1.1
CAS1: IC1.2 (A1), IC2.2 (A1), IC3.10 (B), IC4.10 (B), IC9.10 (B), IC10.10 (B), IC11.2 (B), IC12.2 (A1), IC13.2 (A1), IC16.2 (A1), IC17.2 (A1), J1.2
CAS2: IC1.3 (A2), IC2.3 (A2), IC3.9 (C), IC4.9 (C), IC9.9 (C), IC10.9 (C), IC11.3 (C), IC12.3 (A2), IC13.3 (A2), IC16.3 (A2), IC17.3 (A2), J1.3
CAS3: IC2.4 (!E1), IC4.7 (!OE), IC5.3 (A2), IC10.7 (!OE), IC11.6 (G1), IC13.4 (!E1), IC17.4 (!E1), J1.6
GND: C1.1, C2.1, C3.1, C4.1, C5.1, C6.1, C7.1, C8.1, C9.1, C10.1, C12.1, C13.1, C15.1, C16.1, IC1.8 (GND), IC2.8 (GND), IC3.8 (GND), IC4.8 (GND), IC5.5 (A3), IC5.7 (GND), IC5.9 (A4), IC5.11 (A5), IC6.10 (GND), IC7.10 (GND), IC8.10 (GND), IC9.8 (GND), IC10.8 (GND), IC11.8 (GND), IC12.5 (!E2), IC12.8 (GND), IC13.5 (!E2), IC13.8 (GND), IC16.8 (GND), IC17.8 (GND), J1.8, J3.10, J5.10, J7.10, PAD1.1, PAD14.1, PAD18.1, PAD19.1, R2.2, R3.2
IRQ_OUT: IC9.5 (Y), IC10.5 (Y), PAD3.1
M2_IN: IC12.6 (E3), IC13.6 (E3), PAD2.1
unnamed: IC6.2 (A1), RN3.16
unnamed: IC6.3 (A2), RN3.15
unnamed: IC6.4 (A3), RN3.14
unnamed: IC6.5 (A4), RN3.13
unnamed: IC6.6 (A5), RN3.12
unnamed: IC6.7 (A6), RN3.11
unnamed: IC6.8 (A7), RN3.10
unnamed: IC6.9 (A8), RN3.9
unnamed: J3.2, RN3.1
unnamed: J3.3, RN3.2
unnamed: IC6.11 (B8), J4.10
unnamed: IC6.12 (B7), J4.9
unnamed: IC6.13 (B6), J4.8
unnamed: IC6.14 (B5), J4.7
unnamed: IC6.15 (B4), J4.6
unnamed: IC6.16 (B3), J4.5
unnamed: IC6.17 (B2), J4.4
unnamed: IC6.18 (B1), J4.3
unnamed: IC6.19 (!OE), J4.2
unnamed: J3.4, RN3.3
unnamed: J3.5, RN3.4
unnamed: J3.6, RN3.5
unnamed: J3.7, RN3.6
unnamed: J3.8, RN3.7
unnamed: J3.9, RN3.8
unnamed: IC6.1 (NC), J3.1
unnamed: J7.2, RN5.1
unnamed: IC7.11 (B8), J6.10
unnamed: IC7.12 (B7), J6.9
unnamed: IC7.13 (B6), J6.8
unnamed: IC7.14 (B5), J6.7
unnamed: IC7.15 (B4), J6.6
unnamed: IC7.16 (B3), J6.5
unnamed: IC7.17 (B2), J6.4
unnamed: IC7.18 (B1), J6.3
unnamed: IC7.19 (!OE), J6.2
unnamed: IC8.19 (!OE), J8.2
unnamed: IC8.18 (B1), J8.3
unnamed: IC8.17 (B2), J8.4
unnamed: IC8.16 (B3), J8.5
unnamed: IC8.15 (B4), J8.6
unnamed: IC8.14 (B5), J8.7
unnamed: IC8.13 (B6), J8.8
unnamed: IC8.12 (B7), J8.9
unnamed: IC8.11 (B8), J8.10
unnamed: IC7.5 (A4), RN4.13
unnamed: J5.5, RN4.4
unnamed: J5.2, RN4.1
unnamed: J5.3, RN4.2
unnamed: J5.4, RN4.3
unnamed: J5.6, RN4.5
unnamed: J5.7, RN4.6
unnamed: J5.8, RN4.7
unnamed: J5.9, RN4.8
unnamed: IC11.15 (Y0), J2.2
unnamed: IC11.14 (Y1), J2.3
unnamed: IC11.13 (Y2), J2.4
unnamed: IC11.12 (Y3), J2.5
unnamed: IC11.11 (Y4), J2.6
unnamed: IC11.10 (Y5), J2.7
unnamed: IC11.9 (Y6), J2.8
unnamed: IC11.4 (G2A), J1.4
unnamed: PAD9.1, PAD10.1
unnamed: PAD11.1, PAD12.1
unnamed: IC7.4 (A3), RN4.14
unnamed: IC11.5 (G2B), J1.5
unnamed: IC7.3 (A2), RN4.15
unnamed: IC11.7 (Y7), J1.7
unnamed: IC7.2 (A1), RN4.16
unnamed: IC7.1 (NC), J5.1
unnamed: IC7.6 (A5), RN4.12
unnamed: IC7.7 (A6), RN4.11
unnamed: IC7.8 (A7), RN4.10
unnamed: IC7.9 (A8), RN4.9
unnamed: J7.3, RN5.2
unnamed: J7.5, RN5.4
unnamed: IC8.5 (A4), RN5.13
unnamed: IC8.4 (A3), RN5.14
unnamed: IC8.3 (A2), RN5.15
unnamed: IC8.2 (A1), RN5.16
unnamed: IC8.6 (A5), RN5.12
unnamed: IC8.7 (A6), RN5.11
unnamed: IC8.8 (A7), RN5.10
unnamed: IC8.9 (A8), RN5.9
unnamed: IC8.1 (NC), J7.1
unnamed: J7.4, RN5.3
unnamed: J7.6, RN5.5
unnamed: J7.7, RN5.6
unnamed: J7.8, RN5.7
unnamed: J7.9, RN5.8
unnamed: PAD15.1, R1.1
unnamed: PAD16.1, PAD17.1, R1.2
unnamed: PAD8.1, R2.1
unnamed: PAD7.1, R3.1
PPU_/A13_IN: IC5.12 (Y6), J9.4, J10.26
PPU_/A13_SRAM: IC3.5 (Y), IC4.5 (Y), IC5.1 (A1), PAD4.1
PPU_/RD_IN: IC1.5 (!E2), IC2.5 (!E2), PAD13.1
PPU_A12: IC16.5 (!E2), IC17.5 (!E2), PAD20.1
PPU_A13_IN: IC5.13 (A6), PAD6.1
PPU_A13_LS139: IC5.2 (Y1), PAD5.1
S0_CIRAM: IC4.4 (D0), J9.3
S0_IRQ: IC10.4 (D0), J9.2, RN1.1
S0_M2: IC13.15 (Y0), J9.1
S0_PPU_/RD: IC2.15 (!Y0), J9.5
S0_PPU_A12: IC17.15 (!Y0), J9.6
S1_CIRAM: IC4.3 (D1), J10.3
S1_IRQ: IC10.3 (D1), J10.2, RN1.2
S1_M2: IC13.14 (Y1), J10.1
S1_PPU_/RD: IC2.14 (!Y1), J10.5
S1_PPU_A12: IC17.14 (!Y1), J10.4
S2_CIRAM: IC4.2 (D2), J10.8
S2_IRQ: IC10.2 (D2), J10.7, RN1.3
S2_M2: IC13.13 (Y2), J10.6
S2_PPU_/RD: IC2.13 (!Y2), J10.10
S2_PPU_A12: IC17.13 (!Y2), J10.9
S3_CIRAM: IC4.1 (D3), J10.13
S3_IRQ: IC10.1 (D3), J10.12, RN1.4
S3_M2: IC13.12 (Y3), J10.11
S3_PPU_/RD: IC2.12 (!Y3), J10.15
S3_PPU_A12: IC17.12 (!Y3), J10.14
S4_CIRAM: IC4.15 (D4), J10.18
S4_IRQ: IC10.15 (D4), J10.17, RN1.9
S4_M2: IC13.11 (Y4), J10.16
S4_PPU_/RD: IC2.11 (!Y4), J10.20
S4_PPU_A12: IC17.11 (!Y4), J10.19
S5_CIRAM: IC4.14 (D5), J10.23
S5_IRQ: IC10.14 (D5), J10.22, RN1.8
S5_M2: IC13.10 (Y5), J10.21
S5_PPU_/RD: IC2.10 (!Y5), J10.25
S5_PPU_A12: IC17.10 (!Y5), J10.24
S6_CIRAM: IC4.13 (D6), J11.3
S6_IRQ: IC10.13 (D6), J11.2, RN1.7
S6_M2: IC13.9 (Y6), J11.1
S6_PPU_/RD: IC2.9 (!Y6), J11.5
S6_PPU_A12: IC17.9 (!Y6), J11.4
S7_CIRAM: IC4.12 (D7), J11.8
S7_IRQ: IC10.12 (D7), J11.7, RN1.6
S7_M2: IC13.7 (Y7), J11.6
S7_PPU_/RD: IC2.7 (!Y7), J11.10
S7_PPU_A12: IC17.7 (!Y7), J11.9
S8_CIRAM: IC3.4 (D0), J11.13
S8_IRQ: IC9.4 (D0), J11.12, RN2.1
S8_M2: IC12.15 (Y0), J11.11
S8_PPU_/RD: IC1.15 (!Y0), J11.15
S8_PPU_A12: IC16.15 (!Y0), J11.14
S9_CIRAM: IC3.3 (D1), J11.18
S9_IRQ: IC9.3 (D1), J11.17, RN2.2
S9_M2: IC12.14 (Y1), J11.16
S9_PPU_/RD: IC1.14 (!Y1), J11.20
S9_PPU_A12: IC16.14 (!Y1), J11.19
S10_CIRAM: IC3.2 (D2), J11.23
S10_IRQ: IC9.2 (D2), J11.22, RN2.3
S10_M2: IC12.13 (Y2), J11.21
S10_PPU_/RD: IC1.13 (!Y2), J11.25
S10_PPU_A12: IC16.13 (!Y2), J11.24
S11_CIRAM: IC3.1 (D3), J12.3
S11_IRQ: IC9.1 (D3), J12.2, RN2.4
S11_M2: IC12.12 (Y3), J12.1
S11_PPU_/RD: IC1.12 (!Y3), J12.5
S11_PPU_A12: IC16.12 (!Y3), J12.4
S12_CIRAM: IC3.15 (D4), J12.8
S12_IRQ: IC9.15 (D4), J12.7, RN2.9
S12_M2: IC12.11 (Y4), J12.6
S12_PPU_/RD: IC1.11 (!Y4), J12.10
S12_PPU_A12: IC16.11 (!Y4), J12.9
S13_CIRAM: IC3.14 (D5), J12.13
S13_IRQ: IC9.14 (D5), J12.12, RN2.8
S13_M2: IC12.10 (Y5), J12.11
S13_PPU_/RD: IC1.10 (!Y5), J12.15
S13_PPU_A12: IC16.10 (!Y5), J12.14
S14_CIRAM: IC3.13 (D6), J12.18
S14_IRQ: IC9.13 (D6), J12.17, RN2.7
S14_M2: IC12.9 (Y6), J12.16
S14_PPU_/RD: IC1.9 (!Y6), J12.20
S14_PPU_A12: IC16.9 (!Y6), J12.19
S15_CIRAM: IC3.12 (D7), J12.23
S15_IRQ: IC9.12 (D7), J12.22, RN2.6
S15_M2: IC12.7 (Y7), J12.21
S15_PPU_/RD: IC1.7 (!Y7), J12.25
S15_PPU_A12: IC16.7 (!Y7), J12.24
VCC: C1.2, C2.2, C3.2, C4.2, C5.2, C6.2, C7.2, C8.2, C9.2, C10.2, C12.2, C13.2, C15.2, C16.2, IC1.6 (E3), IC1.16 (VCC), IC2.6 (E3), IC2.16 (VCC), IC3.16 (VCC), IC4.16 (VCC), IC5.14 (VCC), IC6.20 (VCC), IC7.20 (VCC), IC8.20 (VCC), IC9.16 (VCC), IC10.16 (VCC), IC11.16 (VCC), IC12.16 (VCC), IC13.16 (VCC), IC16.6 (E3), IC16.16 (VCC), IC17.6 (E3), IC17.16 (VCC), J2.1, J4.1, J6.1, J8.1, RN1.5, RN2.5

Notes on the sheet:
Replacement ALS245 This is required to allow multiple carts with Extra Ram to not interfere with each other.
Pass-through socket for the ALS138. Many signals are derived from this chip and its easier to remove the chip and put a socket in place and then socket the chip onto the PCB.
Connectors
M2 / φ2 Demultiplexes the CPU clock output.
Enables gamepad on games like Paperboy
NameTables

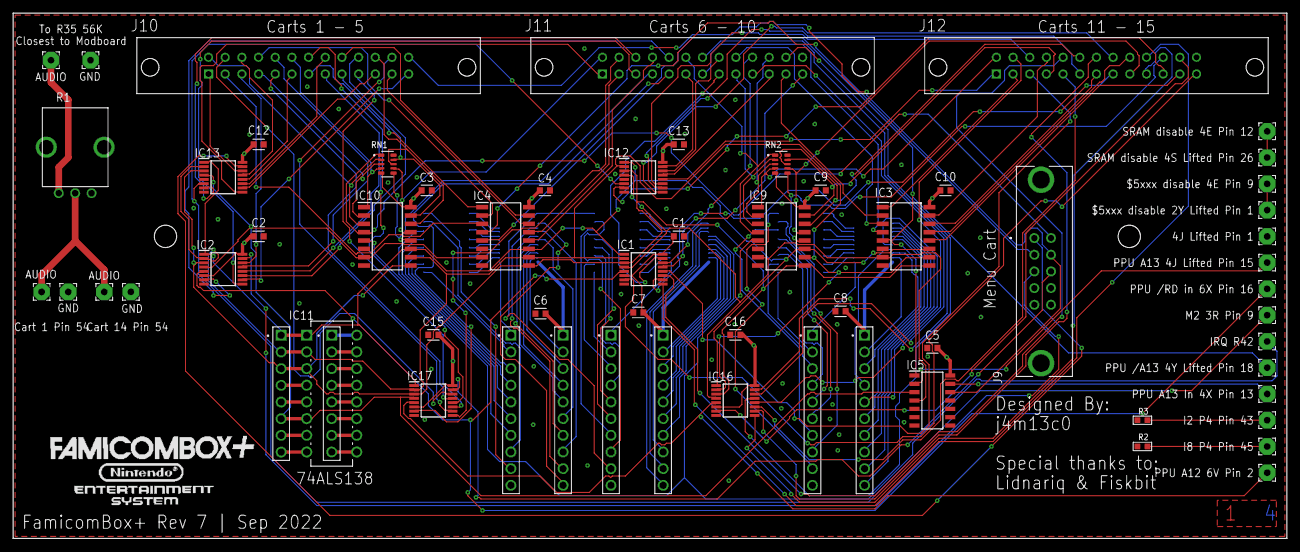
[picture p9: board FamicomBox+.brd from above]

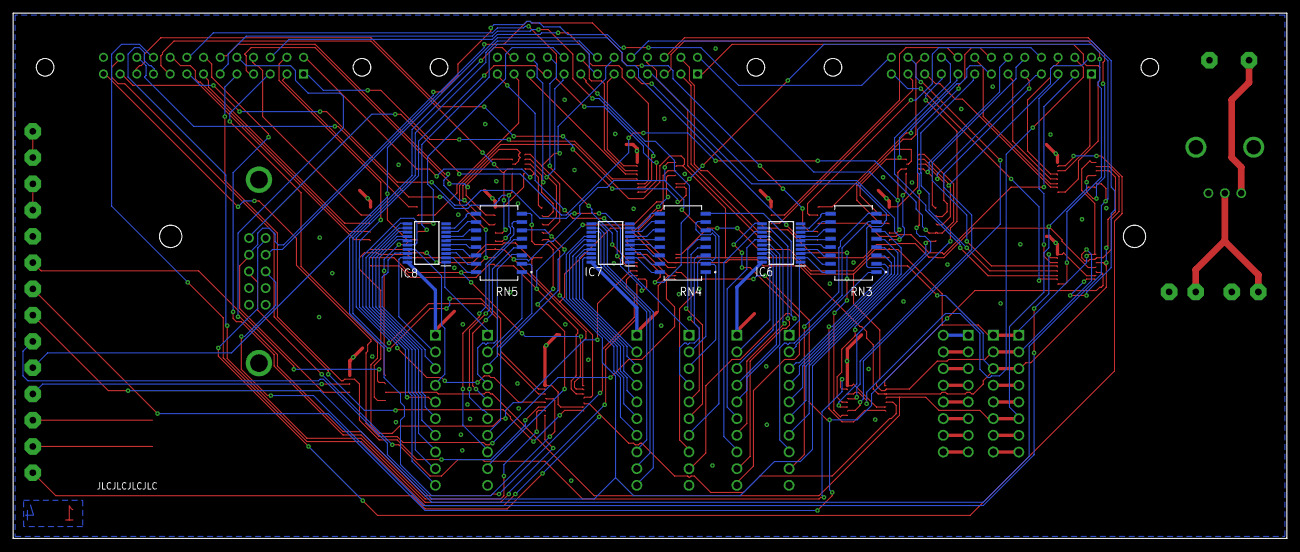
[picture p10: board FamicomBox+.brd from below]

Board: 4 copper layers, 194.0 x 80.0 mm, 69 parts (6 on the bottom side), 189 nets.

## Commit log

2022-09-22 Initial commit
    Initial commit
    [72pin Insert v1.f3d, 72pin Insert v1.stl, Famicom Box Coinbox Cover Large v1.f3d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]
2022-09-22 Fixed Layout
    [SSS_SOB_REPRO.brd, SSS_SOB_REPRO.sch]
2022-09-22 Added BOM
    [FamicomBox+ BOM.csv, SSS_SOB_REPRO BOM.csv]

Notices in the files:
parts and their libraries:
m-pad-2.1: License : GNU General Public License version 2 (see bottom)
